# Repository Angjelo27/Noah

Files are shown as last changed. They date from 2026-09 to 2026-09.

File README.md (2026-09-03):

# NOAH - Offline Emergency First-Aid Terminal

**by American Labs · [american.al](https://american.al)**

NOAH is a fully offline, battery-friendly field terminal that answers emergency
first-aid questions in **Albanian and English**. It runs a local LLM with
retrieval over trusted first-aid references on an NVIDIA Jetson Orin Nano,
displays on a 7.8" e-ink panel, and takes input from a pocket keyboard. No
internet, no cloud, no account - press the button, type the question, get the
steps.

## Why

In an emergency without connectivity - mountains, blackouts, disasters - the
knowledge in books like *Where There Is No Doctor* is life-saving but hard to
search when your hands are shaking. NOAH turns that library into a device you
can ask in your own words, in the language you panic in.

## What it does

- **Ask in Albanian or English**, typed on a small Bluetooth keyboard; language
  is detected automatically and answers come back in the language you asked in.
- **Grounded answers**: a local llama3.2:3b answers strictly from retrieved
  passages of bundled first-aid references (IFRC 2025, WHO PFA, Werner, FEMA,
  FM 21-76 survival manual) - ~4,800 indexed chunks.
- **A deterministic safety layer above the model**: 50 keyword-triggered
  emergency rules with pre-written bilingual warnings (CPR, choking, stroke,
  poisoning, button batteries, ketoacidosis, hanging, chemical eye burns…),
  9 full answer replacements for known model failure modes, a scrubber that
  deletes dangerous model sentences (e.g. "make him vomit", "apply a
  tourniquet"), and a veto system so specific rules silence contradicting
  generic ones. Built and hardened across 13 adversarial audit rounds.
- **E-ink UI** designed for the field: word-at-a-time typing refresh,
  full-screen self-healing repaints, silent suspend on a short button press,
  and a persistent "POWERED OFF" screen (e-ink keeps its image with no power).
- **Runs cold**: boot to ready ≈ 60 s; wake from suspend ≈ 3 s with the model
  still warm; English answers in ~7-18 s, Albanian ~25-40 s (translation
  sandwich via NLLB-200).

## Repository layout

| Folder | Contents |
|---|---|
| [`software/`](software/) | All device code (UI, pipeline, safety layer, driver), systemd units, eval harness. Setup guide in its README. |
| [`hardware/`](hardware/) | [Bill of materials](hardware/BOM.md), [wiring guide](hardware/wiring.md), [assembly notes](hardware/assembly.md). |
| [`3d-models/`](3d-models/) | Printable STLs for the full enclosure (shell, visor, plates, bumpers, fit-test coupons) + the Blender source. |
| [`docs/`](docs/) | [Architecture](docs/architecture.md) and the [safety system](docs/safety-system.md) in detail. |

## Quick start

1. Print the enclosure - see [`3d-models/README.md`](3d-models/README.md).
2. Buy the parts - see [`hardware/BOM.md`](hardware/BOM.md).
3. Wire the panel, button and LEDs - see [`hardware/wiring.md`](hardware/wiring.md).
4. Flash JetPack and install the software - see [`software/README.md`](software/README.md).

## ⚠️ Disclaimer

**NOAH is an experimental, educational DIY project - it is not a medical
device and has not been reviewed or certified by any medical authority.**
Its answers come from a small language model constrained by a hand-built
safety layer; errors, mistranslations and omissions are possible and have
been observed during development. It must never replace professional medical
care, emergency services, or first-aid training. If you build one, have its
output reviewed by a medical professional, and treat it as a backup for
situations where no better help is available. The authors accept no
liability for its use.

The first-aid reference texts are **not** included in this repository for
copyright reasons; the software README lists where to obtain each one.

## License

Code and 3D models: [MIT](LICENSE). The NOAH name and logo belong to
American Labs.

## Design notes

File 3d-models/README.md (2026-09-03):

# 3D models

`NOAH_Terminal.blend` is the Blender source (millimeter scene, 1 unit = 1 mm).
The STLs are exported print-ready in real-world millimeters.

## Parts

| File | Part | Material |
|---|---|---|
| `STL/NOAH_Shell.stl` | Main clamshell body (print whole on ≥300 mm beds) | PETG |
| `Shell_Cuts/ShellV_*, ShellH_*, ShellQ_*` | The same shell pre-cut in halves/quarters for smaller printers - pick ONE scheme | PETG |
| `STL/NOAH_FrontPlate.stl` | Front plate with keyboard bay | PETG |
| `STL/NOAH_Visor.stl` | Screen visor (magnet-mounted) | PETG |
| `STL/NOAH_ScreenRetainer.stl` | Clamps the e-ink panel | PETG |
| `STL/NOAH_BasePlate.stl` | Bottom closure | PETG |
| `STL/NOAH_SidePlate_L.stl` / `_R.stl` | Side plates - **different designs, not mirrors** (L = camo, R = louver vents) | PETG |
| `STL/NOAH_RuggedTrim.stl`, `NOAH_Rugged_Trim.stl` | Edge trim | PETG |
| `STL/NOAH_LED_Lens.stl` | LED light pipe | Clear PETG/PLA |
| `bumpers/*`, `STL/NOAH_Bumper_*`, `STL/NOAH_RubberBumpers.stl` | Corner/edge/drop bumpers | **TPU** |
| `STL/NOAH_SolarTabLock_L/R.stl` | Solar panel retainers | PETG |
| `STL/NOAH_FitCoupon_*.stl` | Tolerance test pieces - **print these first** | any |

## Print settings (starting points)

- PETG: 0.2 mm layers, 4 perimeters, 25-40 % infill on structural parts.
- TPU bumpers: 0.2 mm, 2 perimeters, 15 % gyroid, slow.
- The shell prints without supports in its designed orientation; the visor
  face-down for a clean window edge.
- Run the fit coupons and tune horizontal expansion before the big parts:
  magnet pockets and the screen slot are tolerance-critical.

## Editing the source

The `.blend` targets Blender 4/5. The scene is unit-true (mm); part names
match the STL names. If you regenerate STLs, export with selection-only and
global scale 1.0.

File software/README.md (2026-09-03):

# NOAH software

Everything runs on the Jetson under a single systemd service. Paths assume
user `aldo` with code in `/home/aldo` - either create that user or search
and replace the paths in the `.py` files and service units.

## Components

| File | Role |
|---|---|
| `noah_ui.py` | The device UI: e-ink screens, keyboard input, power-button watcher (suspend / power-off screen), typing refresh, answer pagination. |
| `assistant.py` | Pipeline orchestration: language detect → translate → retrieve → LLM → safety post-processing → translate back. Deterministic small-talk replies. |
| `safety.py` | The deterministic safety layer: 50 bilingual emergency rules, 9 full answer replacements, dangerous-sentence scrubber, rule veto map, medication caution. Self-testing (`python3 safety.py` runs an 83-case matrix). |
| `translator.py` | Albanian↔English via NLLB-200 (CTranslate2 int8), language detection, idiom pre-rewrites, ~150 post-translation corrections. |
| `retrieval.py` | Hybrid retrieval: BM25 + Chroma vectors with reciprocal-rank fusion, query expansions, obsolete-doctrine filter. |
| `eink.py` | IT8951 e-ink driver (SPI + GPIO): 4bpp transfers, partial refresh, controller RAM map, GC16/DU waveforms. |
| `ingest.py` | Builds the vector/BM25 index from the reference PDFs (with a blocklist for outdated medical advice). |
| `recovery_strips.py` | Glass recovery tool: strip-by-strip black/white sweep (run with the service stopped). |
| `system/` | systemd units + logind config. |
| `eval/` | Eval harness + all bilingual question batteries from 13 audit rounds. |
| `tools/` | Controller diagnostics (RAM readback probes). |

## Setup

### 1. Base system

JetPack 6.x (Ubuntu 22.04) on a Jetson Orin Nano 8 GB. Then:

```bash
sudo apt update && sudo apt install -y python3-pip busybox librsvg2-bin
pip3 install chromadb requests pillow numpy rank_bm25 langdetect \
             ctranslate2 transformers sentencepiece Jetson.GPIO spidev
```

### 2. LLM runtime

```bash
curl -fsSL https://ollama.com/install.sh | sh
ollama pull llama3.2:3b
ollama pull nomic-embed-text
```

### 3. Translation model (Albanian)

Convert NLLB-200-distilled-600M to CTranslate2 int8 and place it at
`/data/models/nllb-ct2-int8`:

```bash
pip3 install "ctranslate2" "transformers[torch]"
ct2-transformers-converter --model facebook/nllb-200-distilled-600M \
  --output_dir /data/models/nllb-ct2-int8 --quantization int8
```

### 4. Reference library (not included - copyright)

Create `~/emergency-library/` and add:

- **IFRC International First Aid, Resuscitation and Education Guidelines 2025** - ifrc.org
- **WHO Psychological First Aid: Guide for Field Workers** - who.int
- **Where There Is No Doctor** (David Werner) - free from hesperian.org
- **FEMA "Are You Ready?"** - fema.gov (public domain)
- **FM 21-76 US Army Survival Manual** - public domain; trim to the
  medical/survival chapters to keep retrieval focused

Then build the index (stop ollama models you don't need first - ingest is
memory-hungry):

```bash
python3 ingest.py     # → ~/emergency-db (about 4,800 chunks)
```

### 5. Panel driver quirks (read before first boot)

- Set `VCOM_MV` in `eink.py` to YOUR panel's sticker value.
- The pinmux service is mandatory (see `hardware/wiring.md`).
- SPI stays at 4 MHz; the controller stores every frame as 8 bits/pixel
  internally - its 8 MB RAM fits exactly two frames. Do not add parked
  buffers; do not use partial-area displays from parked slots. These limits
  were mapped the hard way; `tools/` contains the probes that proved them.

### 6. Services

```bash
sudo cp system/noah-ui.service system/fix-gpio-pinmux.service /etc/systemd/system/
sudo mkdir -p /etc/systemd/logind.conf.d
sudo cp system/noah-power-logind.conf /etc/systemd/logind.conf.d/
sudo systemctl daemon-reload
sudo systemctl enable --now fix-gpio-pinmux noah-ui
sudo systemctl restart systemd-logind
```

Pair the BB Q10 keyboard once via `bluetoothctl` (`pair` + `trust`).

## Running the eval

```bash
cd eval
python3 sq_eval_runner.py sq_long_questions.txt /tmp/out.txt
```

`safety.py` doubles as a regression test: `python3 safety.py` must print
`ALL PASS` after any rule change. When you find a new failure mode, the
workflow is: add the rule/pattern + a matrix case + re-run the question -
that loop, repeated over 13 audit rounds, is where the safety layer came from.

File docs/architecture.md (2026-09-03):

# Architecture

```
 keyboard (BT HID) ──► noah_ui.py ──► assistant.answer(question)
                          │                   │
                          │            1. smalltalk? → canned bilingual reply
                          │            2. is_albanian? (word list + langdetect)
                          │            3. sq→en translation (NLLB ct2 int8)
                          │            4. first-person detection → patient stamp
                          │            5. hybrid retrieval (BM25 + Chroma, RRF)
                          │            6. llama3.2:3b via ollama (passages-only
                          │               for emergencies; general knowledge
                          │               allowed for everyday questions)
                          │            7. degeneration + short-answer retries
                          │            8. SAFETY LAYER (safety.py):
                          │               fired_rules → CONTRA replacement →
                          │               danger_scrub → med caution
                          │            9. en→sq translation + ~150 SQ fixes
                          │           10. prepend rule warnings (KUJDES blocks)
                          │                   │
                          ▼                   ▼
                    e-ink display  ◄── paginated answer
                    (IT8951 driver, eink.py)
```

## Key design decisions

- **Determinism above the model.** A 3B model cannot be trusted with
  life-safety edge cases. Every dangerous class discovered in testing became
  a regex-triggered pre-written warning that prints BEFORE the model text,
  independent of what the model says. The model provides depth; the rules
  provide the floor.
- **Translation sandwich.** The LLM never sees Albanian. Albanian in →
  English through NLLB → English answer → Albanian out, with idiom
  pre-rewrites (e.g. "i ra pika" = stroke, not a falling drop) and a large
  post-translation correction table, because a general MT model lacks the
  Albanian medical register.
- **E-ink discipline.** The IT8951 stores frames 8bpp: its 8 MB RAM holds
  exactly two frames (working + parked home). Full-screen single-pass deep
  refreshes exceed the prototype's 5 V wiring, so deep refreshes run as two
  half-screen GC16 passes; typing uses 16px-aligned A2 partial strips with a
  self-healing pass on every return home.
- **Power states.** Short button press = suspend (RAM + warm model kept,
  ~3 s wake). Long press = a persistent "powered off" screen - e-ink keeps
  the image at zero power - then clean shutdown.

## Timings (measured on the prototype)

| Event | Time |
|---|---|
| Cold boot → READY | ~60 s |
| Wake from suspend | ~3 s |
| English answer | 7-18 s |
| Albanian answer | 25-40 s |
| Deep home repaint | ~5.5 s |

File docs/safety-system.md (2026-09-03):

# The safety system

The heart of NOAH is not the language model - it is the deterministic layer
in [`safety.py`](../software/safety.py) that stands between the model and a
person in an emergency. It was built empirically across **13 adversarial
audit rounds** (hundreds of Albanian and English questions, every failure
fixed and locked with a regression test).

## Layers

1. **50 rules.** Each rule is `(name, english_pattern, albanian_pattern,
   english_warning, albanian_warning)`. Patterns run over both the raw
   question and its translation; a hit prepends a pre-written warning block
   before anything the model says. Coverage includes CPR/not-breathing,
   choking (with an explicit "coughing = don't interfere" clause), stroke
   (incl. folk idioms), poisoning (chemicals, pills, mushrooms, cigarettes,
   button batteries), bleeding, tourniquets, burns (thermal/chemical/sun),
   anaphylaxis, spinal, head injury, seizures, febrile seizures, diabetic
   low AND high sugar, hypothermia, frostbite, heatstroke, heat cramps,
   carbon monoxide, hanging, drowning, chest wounds, amputation, pregnancy
   (bleeding and falls), infants, testicular torsion, eye injuries (blunt
   and chemical), jellyfish, sea urchins, panic attacks, and more.
2. **9 CONTRA bodies.** For failure modes where the model was observed
   *commanding* the forbidden action (loosen the tourniquet, make them
   vomit, Heimlich for a stroke or a nose object), the entire model answer
   is replaced by a pre-written safe answer.
3. **danger_scrub.** Sentence-level deletion of known-dangerous model output
   regardless of context: negated-CPR advice, non-negated "make him vomit",
   "stop the birth", model-initiated tourniquets, "help them stand up"
   after falls, prompt echoes, plus a repetition-loop collapse.
4. **Veto map.** A specific rule silences a contradicting generic one
   (jellyfish ▸ burn - sea water vs fresh water; ketoacidosis ▸ hypoglycemia
   - no sugar vs give sugar; fishbone/nose-object ▸ choking).
5. **Medication caution.** Any answer naming prescription drugs gets a
   bilingual "not without a health worker" line appended.

## The regression matrix

`python3 safety.py` runs an 83-case matrix: real user phrasings (including
dialect, diacritic-free typing, reversed word order, first-person forms)
against expected rule sets, plus scrubber unit tests proving that safe
advice ("do NOT make them vomit") survives while dangerous advice is
deleted. **All changes must keep it at ALL PASS.** The matrix has caught
bugs in its own new rules before deployment more than once.

## Notable catches from the audit rounds

These are real outputs the layers now prevent - kept here as a reminder of
why the floor exists:

- "Loosen the tourniquet to let the blood circulate" (model, 3 of 3 runs)
- Heimlich maneuver for a stroke, a fish bone, and a bean in the nose
- "Do not attempt CPR if the person does not respond" (drowning)
- Glucose tablets for blood sugar 400 with acetone breath
- A tourniquet for an infected wound
- Drowning "float on your back" steps for a panic attack
- EpiPen advice for a heart attack
- Fresh-water rinse for a jellyfish sting
- "The device can't help, find somebody to talk to" for "I feel sick"

## Limits - be honest with users

The layer reduces risk; it cannot eliminate it. The model body under a
correct warning can still be clumsy or off-topic; translations still
produce occasional howlers; and no rule exists for classes nobody has
tested yet. Every transcript in `software/eval/` deserves a professional
medical read - if you build on this, continue the audit loop.

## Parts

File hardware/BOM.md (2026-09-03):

# Bill of Materials

| # | Part | Details | Qty |
|---|---|---|-----|
| 1 | **NVIDIA Jetson Orin Nano 8 GB Developer Kit** | The brain. Runs the LLM, translation and retrieval. NVMe SSD strongly recommended (models + index ≈ 10 GB). | 1 |
| 2 | **Waveshare 7.8" e-Paper HAT (B)** | IT8951 controller, 1872 × 1404, 16 grey levels. Panel + driver board + adapter. | 1 |
| 3 | **BB Q10 Bluetooth keyboard module** | BlackBerry Q10 keyboard with a Bluetooth controller board (sold as a DIY module). Pairs as a standard BT HID keyboard. | 1 |
| 4 | **USB-C PD power supply, 65 W with a 15 V profile** | ⚠️ See the power warning in [wiring.md](wiring.md) - cable choice matters. | 1 |
| 5 | **Momentary push button** | Panel-mount, normally-open. Wired to the Jetson's button header: suspend / wake / power-off / power-on. | 1 |
| 6 | **LEDs, 3 mm/5 mm + series resistors (≈330 Ω)** | Power LED and signal ("thinking") LED, front panel via the printed lens. | 2 |
| 7 | **Dupont jumper wires, female-female** | Panel SPI + power harness (10+), button, LEDs. For the permanent build, replace with a soldered harness. | ~20 |
| 8 | **Neodymium disc magnets** | Hold the screen visor to the shell (design uses 7). Size per the pockets in the printed parts - verify with `NOAH_FitCoupon_Magnet.stl` before committing. | 7 |
| 9 | *(Optional)* **Small solar panel** | The shell has integrated solar mounting tabs + printed tab locks. Any thin panel that fits the back recess; feeds a USB power bank, not the Jetson directly. | 1 |
| 10 | *(Optional)* **USB power bank, USB-C PD, 15 V capable** | For true field use. ⚠️ Read the 20 V cable warning in wiring.md **before** battery use. | 1 |

## Print-side consumables

- PETG (or PLA for indoor units) for the shell, visor, plates - see
  [`3d-models/README.md`](../3d-models/README.md).
- TPU for the rubber bumpers (`bumpers/`, `NOAH_RubberBumpers.stl`).
- M2/M3 screws per the boss holes in the shell (verify against your print).

## Tools

- Multimeter - genuinely required once: for continuity checks before the 5 V
  harness reinforcement and for **identifying safe charging cables** (see the
  20 V warning). A cheap one is fine.
- Soldering iron for the permanent harness (the prototype runs on dupont).

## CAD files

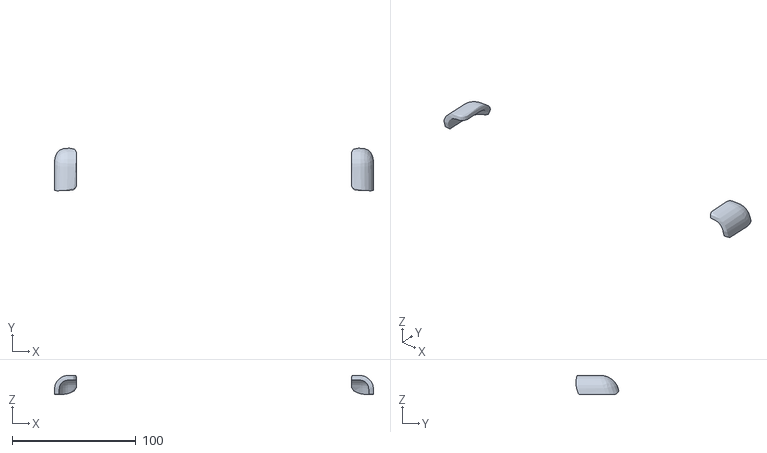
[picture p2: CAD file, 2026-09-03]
3d-models/bumpers/NOAH_Bumper_TopCap.stl
258.0 x 34.5 x 15.6

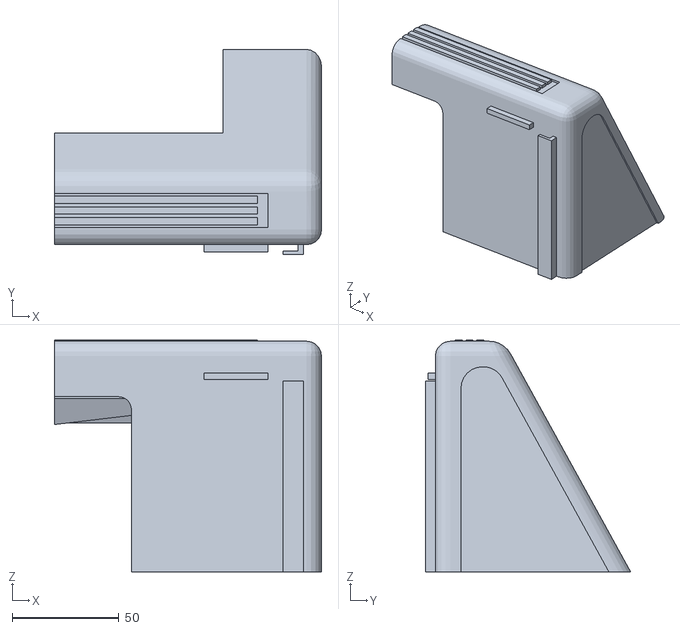
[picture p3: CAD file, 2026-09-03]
3d-models/Shell_Cuts/NOAH_ShellQ_Left_Top.stl
125.0 x 96.2 x 108.5

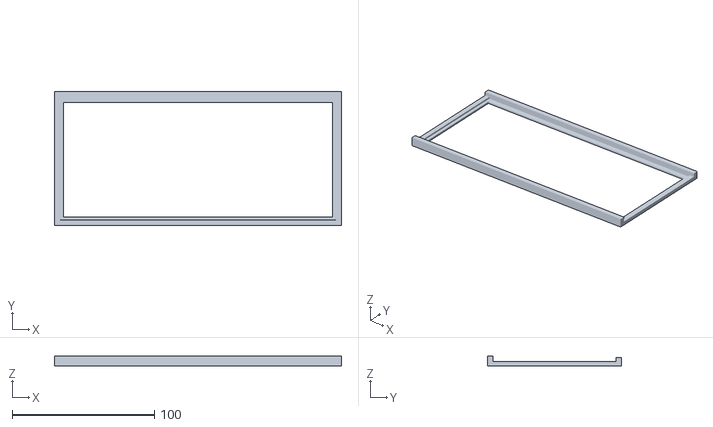
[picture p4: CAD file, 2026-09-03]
3d-models/STL/NOAH_FitCoupon_Keyboard.stl
202.0 x 94.6 x 7.00

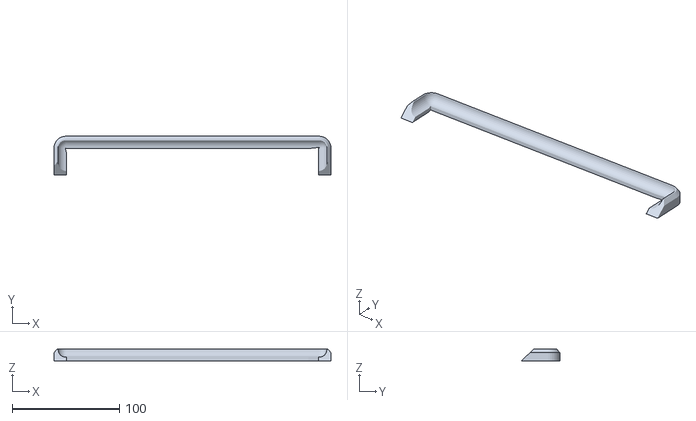
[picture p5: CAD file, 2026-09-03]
3d-models/bumpers/NOAH_Bumper_Bottom.stl
258.0 x 36.0 x 11.0

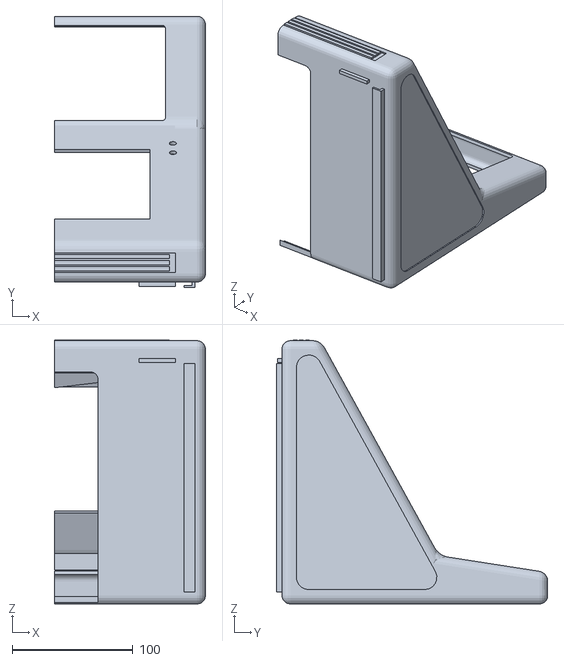
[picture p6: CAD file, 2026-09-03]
3d-models/Shell_Cuts/NOAH_ShellV_Left.stl
125.0 x 224.7 x 218.5

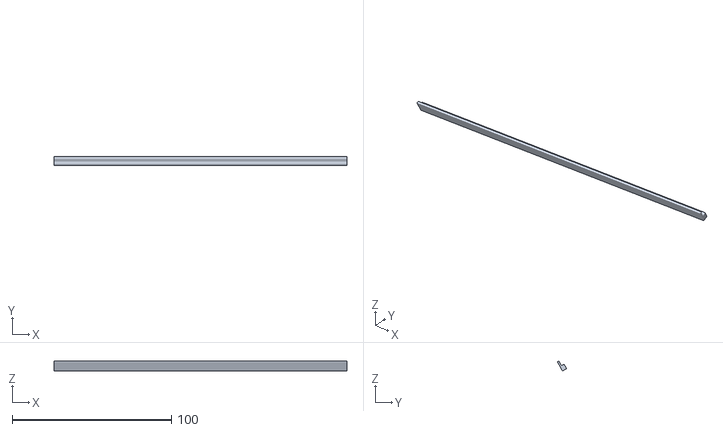
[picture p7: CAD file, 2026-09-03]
3d-models/STL/NOAH_ScreenRetainer.stl
184.0 x 5.79 x 6.27

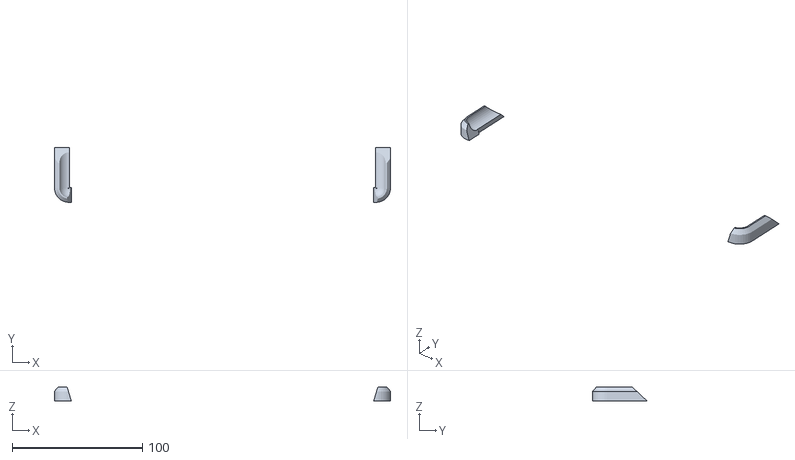
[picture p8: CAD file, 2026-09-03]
3d-models/bumpers/NOAH_Bumper_Back.stl
258.0 x 42.0 x 11.0

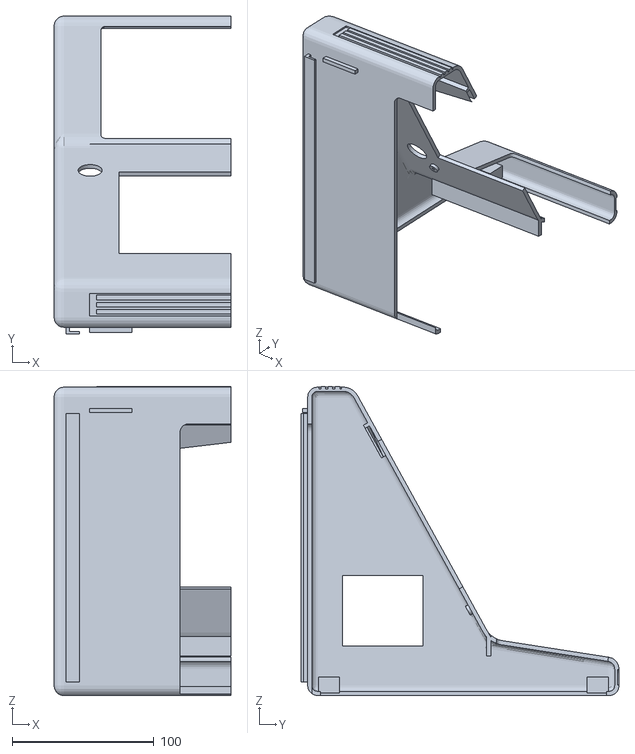
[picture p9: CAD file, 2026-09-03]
3d-models/Shell_Cuts/NOAH_ShellV_Right.stl
125.0 x 224.7 x 218.5

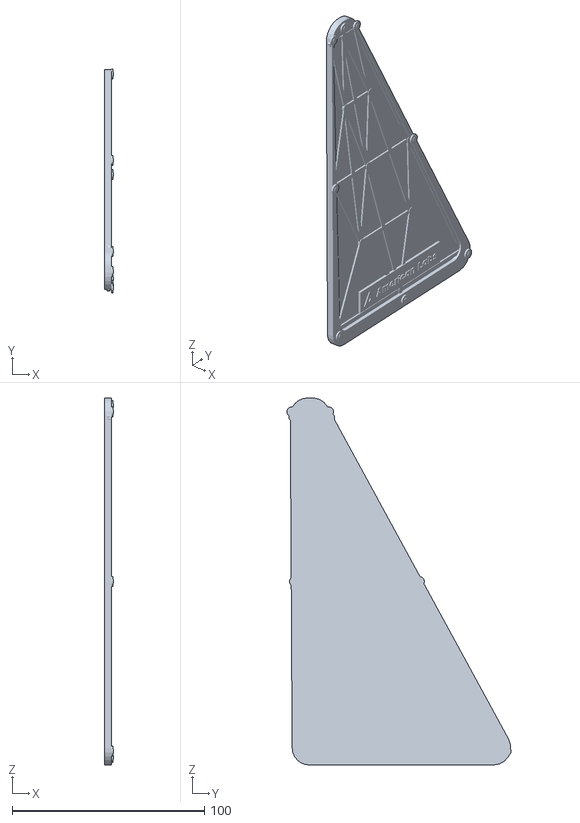
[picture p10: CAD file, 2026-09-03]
3d-models/STL/NOAH_SidePlate_L.stl
4.75 x 116.6 x 190.9

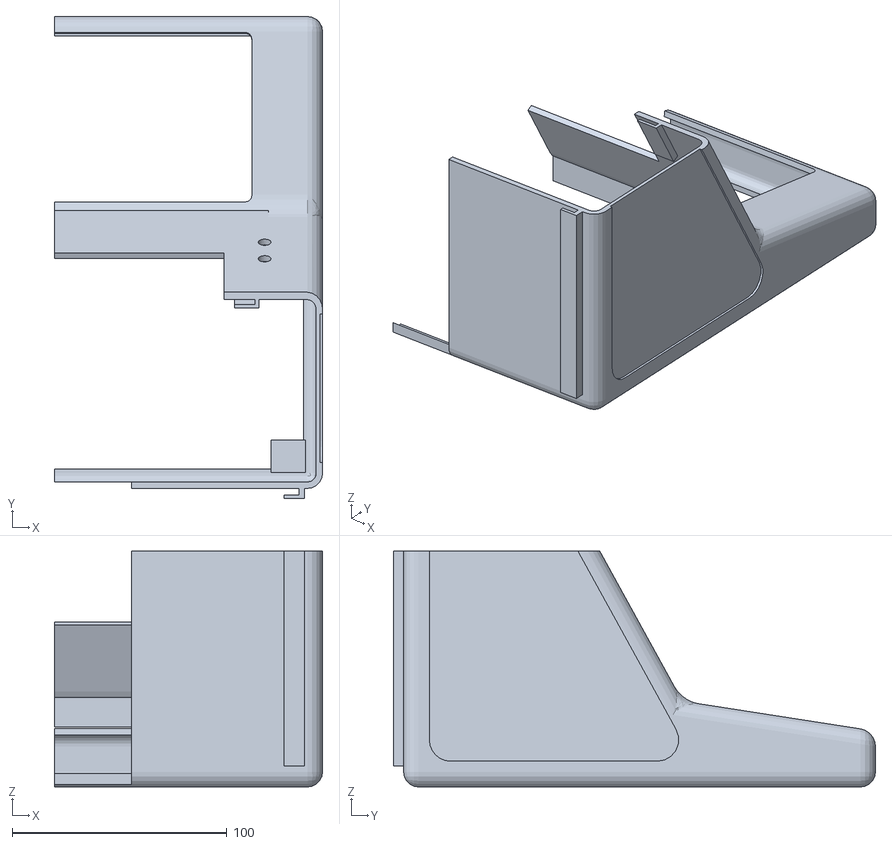
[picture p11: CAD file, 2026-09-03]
3d-models/Shell_Cuts/NOAH_ShellQ_Left_Bottom.stl
125.0 x 224.7 x 110.0

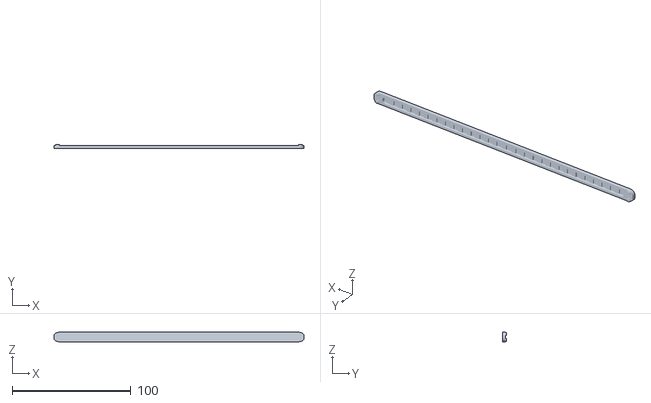
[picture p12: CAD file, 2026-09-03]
3d-models/STL/NOAH_FrontPlate.stl
210.3 x 3.40 x 8.00

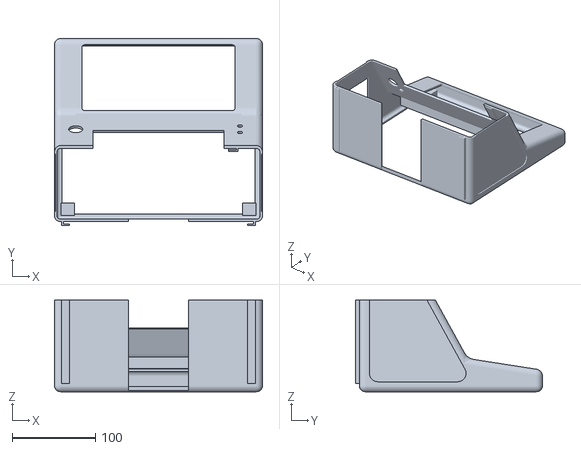
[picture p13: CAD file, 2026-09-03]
3d-models/Shell_Cuts/NOAH_ShellH_Bottom.stl
250.0 x 224.7 x 110.0

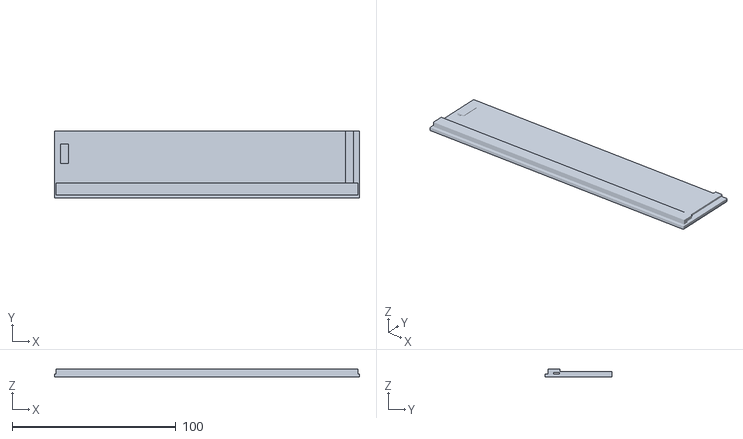
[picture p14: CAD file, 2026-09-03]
3d-models/STL/NOAH_FitCoupon_Screen.stl
186.0 x 41.0 x 5.00

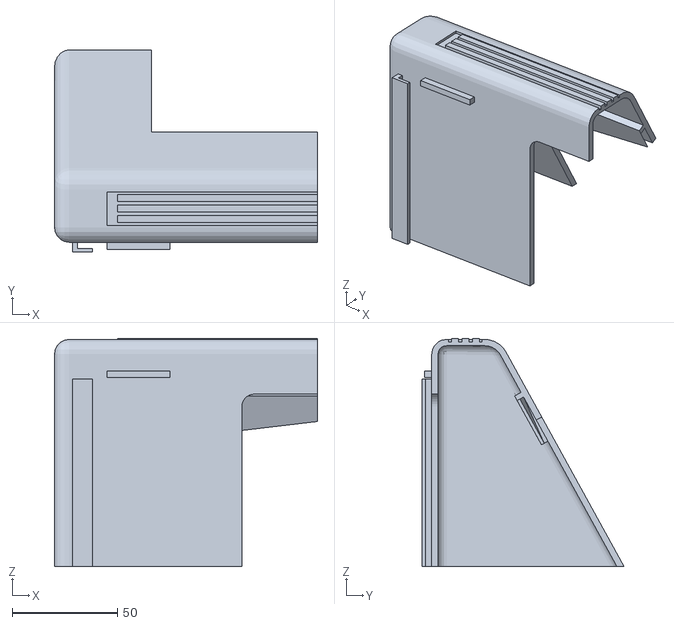
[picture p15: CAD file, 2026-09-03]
3d-models/Shell_Cuts/NOAH_ShellQ_Right_Top.stl
125.0 x 96.2 x 108.5

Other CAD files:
3d-models/STL/NOAH_FitCoupon_Magnet.stl
3d-models/Shell_Cuts/NOAH_ShellQ_Right_Bottom.stl
3d-models/STL/NOAH_SolarTabLock_L.stl
3d-models/Shell_Cuts/NOAH_ShellH_Top.stl
3d-models/NOAH_Terminal.blend
3d-models/STL/NOAH_BasePlate.stl
3d-models/STL/NOAH_FitCoupon_Rails.stl
3d-models/STL/NOAH_LED_Lens.stl
3d-models/STL/NOAH_RubberBumpers.stl
3d-models/STL/NOAH_RuggedTrim.stl
3d-models/STL/NOAH_Rugged_Trim.stl
3d-models/STL/NOAH_Shell.stl
3d-models/STL/NOAH_SidePlate_R.stl
3d-models/STL/NOAH_SolarTabLock_R.stl
3d-models/STL/NOAH_Visor.stl

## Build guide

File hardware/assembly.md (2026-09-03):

# Assembly notes

The enclosure is a printed clamshell: main shell + front plate + screen visor
+ base plate + two side plates + TPU bumpers. Fit is magnet-and-rail based -
no glue on the main joints.

## Before printing everything

Print the **fit coupons first** (`3d-models/STL/NOAH_FitCoupon_*.stl`):
screen, keyboard, magnet and rail coupons. They are small test pieces that
verify your printer's tolerances against the real hardware before you spend
a spool on the shell. Adjust horizontal expansion until the coupons fit
snugly.

## Order of assembly

1. **Dry-fit the electronics** outside the shell first: wire the panel per
   [wiring.md](wiring.md), boot, and confirm the display works. Debugging
   through an assembled shell is misery.
2. **Screen + visor**: the panel sits in the front opening, held by
   `NOAH_ScreenRetainer.stl`; the visor (`NOAH_Visor.stl`) carries the
   window and clicks onto the shell with the 7 magnets (pockets in both
   parts - glue magnets with CA, mind the polarity, check twice before the
   glue sets).
3. **Jetson + driver board** mount inside the main shell (`NOAH_Shell.stl`)
   on the printed rails/bosses. The IT8951 driver board sits behind the
   panel; keep the panel FPC gentle - no sharp folds.
4. **Keyboard bay**: the BB Q10 module drops into the keyboard bay in the
   front plate (`NOAH_FrontPlate.stl`). It is wireless - only its charging
   lead needs routing.
5. **Button + LEDs**: the momentary button mounts in its shell hole and wires
   to the J14 header; the two LEDs sit behind `NOAH_LED_Lens.stl`.
6. **Side plates** (`NOAH_SidePlate_L/R.stl`) - note they are DIFFERENT
   designs, not mirrors: left is the camo plate, right carries the louver
   vents. They close the sides after the harness is in.
7. **Base plate** (`NOAH_BasePlate.stl`) closes the bottom.
8. **Bumpers**: TPU corner/edge bumpers (`bumpers/`, plus
   `NOAH_Bumper_*.stl`) press onto the shell - print them last, they hide
   layer seams and take the drops.
9. *(Optional)* **Solar**: thin panel into the back recess, held by
   `NOAH_SolarTabLock_L/R.stl`.

## Shell print variants

`Shell_Cuts/` contains the shell pre-cut for smaller printers: vertical
halves (`ShellV_*`), horizontal halves (`ShellH_*`), or quarters
(`ShellQ_*`). Pick ONE scheme; the cuts have alignment features. On a
300 mm-class bed, print `NOAH_Shell.stl` whole.

## The cable rule

Whatever harness you build: label the known-good power cable, and keep the
20 V warning from [wiring.md](wiring.md) taped to the battery.

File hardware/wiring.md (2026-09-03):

# Wiring guide

All references are to the Jetson Orin Nano Developer Kit. Header pins are
counted from the printed "1" on the carrier board (odd/even rows). **Never
connect or disconnect anything with power applied.**

## 1. E-ink panel (Waveshare IT8951 HAT (B))

The HAT is *not* stacked on the 40-pin header - it is wired with individual
jumpers so the enclosure can position it freely. The HAT header follows the
Raspberry Pi layout, so pin numbers match on both ends.

| Signal | Jetson 40-pin | HAT pin | Notes |
|---|---|---|---|
| 5V | pin 2 (and 4) | 5V (2/4) | ⚠️ One jumper sags under load - see §4. |
| GND | pin 6 (add 9/14) | GND (6/9/14) | More grounds = better. |
| SCK | pin 23 (SPI1_SCK) | CLK | 4 MHz max on jumper wiring - 12 MHz corrupts commands. |
| MOSI | pin 19 (SPI1_MOSI) | DIN | |
| MISO | pin 21 (SPI1_MISO) | DOUT | |
| CS | pin 24 | CS | Driven as GPIO (gpiochip0 line 136), not hardware CS. |
| RST | pin 11 | RST | gpiochip0 line 112. |
| BUSY (HRDY) | pin 13 | BUSY | gpiochip0 line 122. |

Panel specifics baked into the driver ([`software/eink.py`](../software/eink.py)):
VCOM **−1.58 V** (read your own panel's sticker and change `VCOM_MV`!),
SPI 4 MHz, 4-bits-per-pixel transfers.

**Pinmux is mandatory.** JetPack boots these pads in the wrong function; the
included [`fix-gpio-pinmux.service`](../software/system/fix-gpio-pinmux.service)
writes the pad registers with `busybox devmem` at every boot (SPI1 pads to
SFIO, CS and RST to GPIO, LED pads). Without it the panel reads all zeros.
Do not rely on `jetson-io` overlays - on this system they silently fail to
apply at boot.

## 2. Power button

A momentary switch across the **PWR BTN ↔ GND pins of the 12-pin button
header (J14)**. Behavior is implemented in software (`noah_ui.py` watches the
key events; systemd-logind is told to ignore the key):

- Short press: silent suspend / wake (model stays warm, ~3 s to usable).
- Hold ≈ 3 s: draws a persistent "FIKUR · POWERED OFF" screen, then clean
  shutdown. The image stays on the e-ink while the device is off.
- Short press while off: powers back on.

## 3. LEDs

| LED | Jetson pin (BOARD) | Notes |
|---|---|---|
| Power | 31 | Series resistor ≈ 330 Ω to GND. |
| Signal ("thinking") | 7 | Blinks while an answer is being generated. |

Both shine through the printed `NOAH_LED_Lens.stl`.

## 4. Power - read this twice

- Supply: USB-C PD, **15 V profile** (65 W class). The Jetson barrel/USB-C
  input takes it directly.
- ⚠️ **The 20 V cable trap.** Some USB-C cable + supply combinations negotiate
  **20 V**, which is above the dev kit's rating. During development one cable
  was found doing exactly that. Before running from any battery or new
  supply: verify the negotiated voltage with a USB-C power meter or
  multimeter, and physically mark known-good cables. Never power NOAH from
  an unverified cable.
- ⚠️ **5 V panel feed.** The e-ink drive current over a single 5 V jumper
  causes voltage sag: full-screen deep refreshes abort, and at the worst
  point half-screen refreshes failed silently. The software works around it
  (half-screen deep refreshes only), but the real fix is copper: run 5 V
  from **both** pin 2 and pin 4 and grounds from pins 6 + 9 + 14 (parallel
  jumpers), or better, a soldered harness. After reinforcement, the software
  can be switched to single-pass full-screen refreshes.

## 5. Assembly order

See [assembly.md](assembly.md).

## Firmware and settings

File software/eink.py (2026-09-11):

#!/usr/bin/env python3
"""NOAH e-ink renderer - IT8951 (7.8" 1872x1404) over SPI on Jetson Orin Nano.

Proven protocol recipe (2026-08-26 bring-up):
  * 4 MHz SPI max on current wiring; wait HRDY before EVERY preamble
  * bulk pixel writes framed per 2 KB chunk (preamble each chunk)
  * displays via DPY_BUF_AREA 0x0037 only (0x0034 dies after first use)
  * VCOM must be programmed (-1.58 V) every panel power-on
  * DU (mode 1) / A2 (mode 6) complete on current 5 V wiring; full-screen
    GC16 (mode 2) aborts until the power feed is upgraded - use DU for text.

Usage:
    from eink import EInk
    epd = EInk()
    pages = epd.paginate_text(answer, title=question, footer="sources: ...")
    epd.show(pages[0])          # DU refresh, auto ghost management
    epd.close()

CLI self-test:  sudo python3 eink.py ["text to render"]
"""
import re, time
import spidev, gpiod
import numpy as np
from PIL import Image, ImageDraw, ImageFont

RST_LINE, CS_LINE, BUSY_LINE = 112, 136, 122     # gpiochip0 (pins 11 / 24 / 13)
VCOM_MV = 1580                                    # panel sticker: -1.58 V
SPI_HZ = 4000000
W, H = 1872, 1404

MODE_INIT, MODE_DU, MODE_GC16, MODE_A2 = 0, 1, 2, 6

FONT_DIR = "/usr/share/fonts/truetype/dejavu/"
MARGIN, TITLE_SIZE, BODY_SIZE, FOOT_SIZE = 118, 48, 40, 28  # 118px = 1cm @ 300dpi
LINE_PITCH = 54
GHOST_FLUSH_EVERY = 8      # white-flush before every Nth refresh


class EInk:
    def __init__(self, vcom=VCOM_MV, spi_hz=SPI_HZ):
        # Null the handles first so a failure partway can release cleanly. An
        # early-boot init can hit a transient EBUSY (the SPI1 pads are still
        # settling right after the pinmux switch): if that happens AFTER the
        # gpio lines are requested, leaving them held would make every retry
        # fail with EBUSY on our own lines. Release on any init failure.
        self._chip = self._rst = self._cs = self._busy = self._spi = None
        try:
            self._chip = gpiod.Chip("gpiochip0")
            self._rst = self._chip.get_line(RST_LINE)
            self._cs = self._chip.get_line(CS_LINE)
            self._busy = self._chip.get_line(BUSY_LINE)
            self._rst.request(consumer="eink", type=gpiod.LINE_REQ_DIR_OUT, default_vals=[1])
            self._cs.request(consumer="eink", type=gpiod.LINE_REQ_DIR_OUT, default_vals=[1])
            self._busy.request(consumer="eink", type=gpiod.LINE_REQ_DIR_IN)
            self._spi = spidev.SpiDev()
            self._spi.open(0, 0)
            self._spi.mode = 0
            self._spi.max_speed_hz = spi_hz
            self.refreshes = 0

            # Reset + boot, then read device info. BOTH the wake (HRDY) and the
            # GET_DEV_INFO read can glitch at cold boot: a desynced SPI read
            # returns shifted words (observed: height read back as 1872 instead
            # of 1404), which used to FATAL the whole UI and force a restart.
            # Retry the entire reset -> SYS_RUN -> GET_DEV_INFO on a bad read.
            info = None
            for attempt in range(4):
                self._rst.set_value(0); time.sleep(0.2)
                self._rst.set_value(1); time.sleep(0.1)
                try:
                    self._ready(4.0)
                except RuntimeError:
                    if attempt == 3:
                        raise RuntimeError("IT8951 not ready after 4 reset attempts")
                    continue
                self._wcmd(0x0001)                   # SYS_RUN
                self._wcmd(0x0302)                   # GET_DEV_INFO
                info = self._rdata(20)
                if (info[0], info[1]) == (W, H) and ((info[3] << 16) | info[2]):
                    break                            # good, synced read
                if attempt == 3:
                    raise RuntimeError("bad device info after 4 tries: %s" % info[:4])
                time.sleep(0.15)                     # desynced read: reset & retry
            self.width, self.height = info[0], info[1]
            self.imgbuf = (info[3] << 16) | info[2]
            self._wreg(0x0004, 0x0001)               # I80CPCR: packed write
            self._wcmd(0x0039); self._wdata(0x0001); self._wdata(vcom)   # set VCOM
        except BaseException:
            self._release_partial()
            raise

        self._fonts = {
            "title": ImageFont.truetype(FONT_DIR + "DejaVuSans-Bold.ttf", TITLE_SIZE),
            "body":  ImageFont.truetype(FONT_DIR + "DejaVuSans.ttf", BODY_SIZE),
            "foot":  ImageFont.truetype(FONT_DIR + "DejaVuSansMono.ttf", FOOT_SIZE),
        }

    def _release_partial(self):
        """Release whatever __init__ managed to acquire, on a failed init."""
        try:
            if self._spi is not None:
                self._spi.close()
        except Exception:
            pass
        for ln in (self._rst, self._cs, self._busy):
            try:
                if ln is not None:
                    ln.release()
            except Exception:
                pass
        try:
            if self._chip is not None:
                self._chip.close()
        except Exception:
            pass

    # ---------- low-level protocol ----------
    def _ready(self, tmo=6.0):
        t0 = time.time()
        while time.time() - t0 < tmo:
            if self._busy.get_value() == 1:
                return
        raise RuntimeError("IT8951 HRDY timeout")

    def _frame(self, preamble, payload):
        self._ready(); self._cs.set_value(0)
        self._spi.xfer2(list(preamble)); self._ready()
        self._spi.xfer2(list(payload)); self._cs.set_value(1)

    def _wcmd(self, v):  self._frame((0x60, 0x00), (v >> 8, v & 0xFF))
    def _wdata(self, v): self._frame((0x00, 0x00), (v >> 8, v & 0xFF))

    def _rdata(self, n):
        self._ready(); self._cs.set_value(0)
        self._spi.xfer2([0x10, 0x00]); self._ready()
        self._spi.xfer2([0, 0]); self._ready()
        raw = self._spi.xfer2([0] * (2 * n)); self._cs.set_value(1)
        return [(raw[i] << 8) | raw[i + 1] for i in range(0, 2 * n, 2)]

    def _wreg(self, a, v): self._wcmd(0x0011); self._wdata(a); self._wdata(v)
    def _rreg(self, a):    self._wcmd(0x0010); self._wdata(a); return self._rdata(1)[0]

    # ---------- image path ----------
    def _load(self, img, x=0, y=0, addr=None):
        """img: np.uint8 (h, w), row-major, 0=black 255=white. 4bpp transfer
        (half the bytes of 8bpp - text is thresholded B/W, no quality loss)."""
        h, w = img.shape
        addr = self.imgbuf if addr is None else addr
        self._wreg(0x0208, addr & 0xFFFF)
        self._wreg(0x020A, addr >> 16)
        self._wcmd(0x0021)                       # LD_IMG_AREA
        for v in (0x0020, x, y, w, h):           # little-endian, 4bpp, rot0
            self._wdata(v)
        nib = (img >> 4).astype(np.uint8)        # 0x0 / 0xF
        packed = (nib[:, 0::2] | (nib[:, 1::2] << 4)).tobytes()
        data = np.frombuffer(packed, dtype="<u2").byteswap().tobytes()
        for off in range(0, len(data), 2048):
            self._ready(); self._cs.set_value(0)
            self._spi.xfer2([0x00, 0x00]); self._ready()
            self._spi.writebytes(data[off:off + 2048])
            self._cs.set_value(1)
        self._wcmd(0x0022)                       # LD_IMG_END

    def _display(self, mode, x=0, y=0, w=W, h=H, tmo=20.0, addr=None):
        addr = self.imgbuf if addr is None else addr
        self._wcmd(0x0037)                       # DPY_BUF_AREA
        for v in (x, y, w, h, mode, addr & 0xFFFF, addr >> 16):
            self._wdata(v)
        t0 = time.time(); first = last = None
        while time.time() - t0 < tmo:
            if self._rreg(0x1224):
                t = time.time() - t0
                if first is None: first = t
                last = t
            elif first is not None and (time.time() - t0 - last) > 0.5:
                break
        return 0.0 if first is None else last - first

    def clear(self):
        """Full white via double DU pass (works on current power wiring)."""
        white = np.full((H, W), 0xFF, dtype=np.uint8)
        self._load(white)
        self._display(MODE_DU)
        self._display(MODE_DU)

    def show(self, img, mode=MODE_DU):
        """Load and display a full frame with automatic ghost management."""
        if self.refreshes and self.refreshes % GHOST_FLUSH_EVERY == 0:
            self.clear()
        self._load(img)
        dur = self._display(mode)
        self.refreshes += 1
        return dur

    # --- dual-buffer page slots: preload while reading, flip in ~0.5s ---
    SLOT_STRIDE = 0x290000  # TRUE 8bpp frame footprint 0x281AC0 + pad. RAM fits ONLY slots 0 (imgbuf) and 1 - see 2026-08-29 probe; never add more

    def load_page(self, img, slot=0):
        self._load(img, addr=self.imgbuf + slot * self.SLOT_STRIDE)

    def show_slot(self, slot=0, mode=MODE_DU):
        return self._display(mode, addr=self.imgbuf + slot * self.SLOT_STRIDE)

    def deep_clean(self):
        """Two half-screen GC16 passes - heavier ghost flush (half current draw)."""
        white = np.full((H, W), 0xFF, dtype=np.uint8)
        self._load(white)
        self._display(MODE_GC16, 0, 0, W, H // 2)
        self._display(MODE_GC16, 0, H // 2, W, H // 2)

    def close(self):
        # No STANDBY: wake-from-standby proved flaky; idle draw is acceptable
        # and the field device will gate panel power in hardware anyway.
        self._spi.close()
        for ln in (self._rst, self._cs, self._busy):
            ln.release()
        self._chip.close()

    # ---------- text rendering ----------
    def _wrap(self, draw, text, font, maxw):
        lines = []
        for raw in text.split("\n"):
            if not raw.strip():
                lines.append("")
                continue
            m = re.match(r"^(\s*(?:\d+[.)]\s+|[-*•]\s+)?)", raw)
            hang = " " * max(2, len(m.group(1))) if m.group(1).strip() else ""
            words, cur = raw.split(), ""
            firstline = True
            for wd in words:
                cand = (cur + " " + wd).strip() if cur else (wd if firstline else hang + wd)
                probe = cand if firstline else cand
                if draw.textlength(probe, font=font) <= maxw or not cur:
                    cur = cand
                else:
                    lines.append(cur)
                    firstline = False
                    cur = hang + wd
            lines.append(cur)
        return lines

    def paginate_text(self, text, title=None, footer=None):
        """Render text into 1..N full-frame numpy pages (thresholded B/W)."""
        probe = ImageDraw.Draw(Image.new("L", (8, 8)))
        maxw = W - 2 * MARGIN
        body_lines = self._wrap(probe, text, self._fonts["body"], maxw)

        top = MARGIN
        title_lines = []
        if title:
            title_lines = self._wrap(probe, title.strip(), self._fonts["title"], maxw)[:2]
            top += len(title_lines) * (TITLE_SIZE + 10) + 26
        usable = H - top - (FOOT_SIZE + 30 + MARGIN)
        per_page = max(1, usable // LINE_PITCH)
        chunks = [body_lines[i:i + per_page] for i in range(0, len(body_lines), per_page)] or [[]]

        pages = []
        for pi, chunk in enumerate(chunks):
            im = Image.new("L", (W, H), 255)
            d = ImageDraw.Draw(im)
            y = MARGIN
            for tl in title_lines:
                d.text((MARGIN, y), tl, font=self._fonts["title"], fill=0)
                y += TITLE_SIZE + 10
            if title_lines:
                d.line((MARGIN, y + 6, W - MARGIN, y + 6), fill=0, width=4)
                y += 26
            for ln in chunk:
                d.text((MARGIN, y), ln, font=self._fonts["body"], fill=0)
                y += LINE_PITCH
            fy = H - MARGIN - FOOT_SIZE
            avail = maxw
            n = len(chunks)
            foot_txt = footer
            if n > 1:                            # multi-page: counter + nav hint
                pg = "%d/%d" % (pi + 1, n)
                pgw = probe.textlength(pg, font=self._fonts["foot"])
                d.text((W - MARGIN - pgw, fy), pg, font=self._fonts["foot"], fill=0)
                avail = maxw - pgw - 60
                if pi < n - 1:                   # a next page exists
                    foot_txt = "ENTER/SPACE = tjetra / next"
                    if pi > 0:                   # ...and a previous page
                        foot_txt += "   P = mbrapa / prev"
                else:                            # last page
                    foot_txt = "P = mbrapa / prev   ENTER = kthehu / back"
            if foot_txt:
                ftxt = foot_txt
                if probe.textlength(ftxt, font=self._fonts["foot"]) > avail:
                    while ftxt and probe.textlength(ftxt + "…", font=self._fonts["foot"]) > avail:
                        ftxt = ftxt[:-1]
                    ftxt += "…"
                d.text((MARGIN, fy), ftxt, font=self._fonts["foot"], fill=0)
            arr = np.frombuffer(im.tobytes(), dtype=np.uint8).reshape(H, W)
            pages.append(np.where(arr > 160, 255, 0).astype(np.uint8))
        return pages


if __name__ == "__main__":
    import sys
    sample = sys.argv[1] if len(sys.argv) > 1 else (
        "Cool the burn immediately with clean, cool running water.\n\n"
        "1. Hold the burned area under cool (not icy) running water for at least 20 minutes.\n"
        "2. Remove rings, watches and tight clothing near the burn before it swells.\n"
        "3. Do NOT apply ice, butter, toothpaste or any ointment to the burn.\n"
        "4. Cover the burn loosely with a clean, non-fluffy cloth or cling film.\n"
        "5. Give the person small sips of water if they are alert.\n\n"
        "Seek professional medical help if the burn is larger than the person's palm, "
        "is on the face, hands or joints, looks white or charred, or if the person "
        "shows signs of shock: pale skin, rapid breathing, confusion.")
    epd = EInk()
    print("panel %dx%d ready, rendering test page..." % (epd.width, epd.height))
    pages = epd.paginate_text(
        sample, title="How do I treat a burn?",
        footer="sources: IFRC International First Aid, Resuscitation and Education "
               "Guidelines 2025, Where_There_Is_No_Doctor_A_Village_Health_Care_Handbook")
    t0 = time.time()
    dur = epd.show(pages[0])
    print("page 1/%d shown (load+refresh %.1fs, engine %.1fs)" % (len(pages), time.time() - t0, dur))
    epd.close()
    print("PASS - the panel should show a formatted first-aid page")

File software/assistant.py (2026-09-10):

import os, re, requests, chromadb, threading, time
import Jetson.GPIO as GPIO
import sys
sys.path.insert(0, "/home/aldo/.local/lib/python3.10/site-packages")  # sudo cant see user pip
import translator
import safety
import retrieval

DB_PATH = "/home/aldo/emergency-db"
OLLAMA = "http://localhost:11434"
MODEL = "llama3.2:3b"          # multilingual (Albanian); was llama3.2:3b
TOP_K = 4
LED_SIGNAL = 7
LED_POWER = 31

SYSTEM_PROMPT = """You are NOAH, an offline emergency first-aid assistant running on a device with no internet access. Your EMERGENCY answers must be drawn ONLY from the reference passages provided below.

FIRST classify the message:
- EMERGENCY: an injury, illness, symptom, accident, or danger happening now. Follow ALL the emergency rules below.
- GENERAL: prevention, supplies, training, everyday habits (food, drink, coffee, sleep, exercise), or general health knowledge. Answer with a short informative paragraph of 4-8 sentences (or a few bullet points): the key facts, practical amounts and numbers, and one or two useful extras such as what to avoid or when it matters. Never answer a GENERAL question with a single sentence. Do not use the emergency format - no urgent-action opener, no numbered emergency steps, no warning-signs section. For GENERAL questions only: if the reference passages are not relevant to the question, IGNORE them completely and answer from ordinary general knowledge - never force emergency framing into an everyday question (no "in emergency situations" talk unless the user described an emergency). Questions about you ("what can you do", "who are you", "how do you work") get 1-2 sentences describing what you are - an offline first-aid guide that answers emergency questions in Albanian and English - NEVER first-aid instructions, even if the reference passages contain them.

TONE, always: straight to the point and factual. No sympathy lines, no reassurance filler ("stay calm", "I am worried about you"), no apologies, no praise, no exclamation marks, no chit-chat. Every sentence must carry an instruction or a fact.

PERSPECTIVE, always: match who is affected. If the user describes THEIR OWN symptoms ("I feel sick", "my arm is bleeding", "I am dizzy"), speak directly to them as "you" - never about "the person", "him", "her", "the victim" or "the patient". If they describe someone else's emergency, give the user the helper's instructions. NEVER deflect with "find someone to help you", "ask someone else" or "talk to somebody" - the user has only this device; always give the actual steps themselves.

EMERGENCY RULES:
1. Answer ONLY using the reference passages. Never invent facts, procedures, medication names, or doses. If the passages give a specific number, use it exactly.
2. If the passages do not cover the situation, say clearly: "My references don't cover this specific situation." Then give the safest general action and state that professional medical help is needed.
3. Start with the single most urgent action in one short sentence. ONLY IF the question asks whether to do something ("should I...", "can I...", "is it safe to...") begin with "Yes" or "No" and the reason. For any other question do NOT begin with the word "Yes" or "No" - begin directly with the action itself. A prohibition like "Do NOT pull it out" counts as the urgent action.
4. Then give numbered steps in the order they must be done. One action per step. Short sentences. Commands, not suggestions.
5. Use plain language a scared non-expert can follow. Translate medical terms. NEVER drop a "do not" warning from the passages.
6. If the passages contain conflicting advice, prefer the IFRC 2025 guidelines over older sources. Older techniques like induced vomiting for poisoning or loosening tourniquets are outdated - do not recommend them.
7. End by stating when to seek professional medical help and warning signs of worsening.
8. Users may type short, misspelled, panicked fragments. Interpret them charitably. Do not ask clarifying questions unless dangerously ambiguous.
9. If the message suggests the person is unconscious, not breathing, or bleeding heavily, address that first.
10. Do not provide guidance for deliberately harming any person.
11. Never begin with "I'm sorry", "I can't", or "I'm not a medical professional".
12. Two absolute rules: (a) In a severe allergic reaction (face or throat swelling, wheezing after a sting) with an epinephrine auto-injector available, helping the person use it IMMEDIATELY is always correct - never advise waiting for permission. (b) A tourniquet that has been applied must NEVER be loosened or removed outside a medical facility."""

# Small talk answered deterministically - no RAG, no LLM, no MT. A 3B model
# with a context full of emergency passages cannot be trusted to classify
# "how are u" reliably (observed: it fell back to "my references don't cover
# this"). Full-string match only, so real questions are never hijacked.
_ST_SQ = (r"pershendetje|përshëndetje|tungjatjeta|tung|ckemi|ç'?kemi"
          r"|mir[ëe]mbr[ëe]ma|mir[ëe]m[ëe]ngjes\w*|mir[ëe]dita"
          r"|si je(ni)?|si kalon(i)?|a je mir[ëe]|faleminderit|flm|rrofsh"
          r"|kush je( ti)?|[çc]far[ëe] je ti|[çc]far[ëe] di t[ëe] b[ëe]sh|si punon")
_ST_EN = (r"hello|hi|hey|good (morning|evening|afternoon)|how are (you|u)|how r u"
          r"|what'?s up|thank you|thanks|thx|who are (you|u)|what are (you|u)"
          r"|what can (you|u) do|how do (you|u) work")
_ST_FULL = re.compile(r"^(\s*(%s|%s)[\s,!.?]*)+$" % (_ST_SQ, _ST_EN), re.IGNORECASE)


def _smalltalk(q):
    t = (q or "").strip().lower()
    if not t or len(t) > 60 or not _ST_FULL.match(t):
        return None
    sq = bool(re.search(_ST_SQ, t, re.IGNORECASE))
    if re.search(r"kush je|[çc]far[ëe] (je|di)|si punon|who are|what (are|can)|how do", t, re.IGNORECASE):
        return ("Jam NOAH - udhëzues i ndihmës së parë pa internet, në shqip dhe anglisht. "
                "Shkruaj pyetjen e urgjencës dhe shtyp ENTER." if sq else
                "I am NOAH - an offline first-aid guide in Albanian and English. "
                "Type your emergency question and press ENTER.")
    if re.search(r"faleminderit|flm|rrofsh|thank|thx", t, re.IGNORECASE):
        return ("S'ka gjë. Jam këtu nëse të duhet ndihmë." if sq else
                "You're welcome. I'm here if you need help.")
    return ("Mirë. Jam NOAH, udhëzuesi i ndihmës së parë. Shkruaj pyetjen dhe shtyp ENTER."
            if sq else
            "Fine. I am NOAH, the first-aid guide. Type your question and press ENTER.")
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

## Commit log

2026-09-03 NOAH offline first-aid terminal: software, hardware docs, 3D models
    Complete DIY build: Jetson Orin Nano + 7.8" e-ink IT8951 + BB Q10 keyboard.
    Bilingual (Albanian/English) offline RAG over first-aid references with a
    50-rule deterministic safety layer, e-ink field UI, printable enclosure.
    [NOAH_BasePlate.stl, NOAH_Bumper_Back.stl, NOAH_Bumper_Bottom.stl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]
2026-09-03 Replace em/en dashes with hyphens across all text
    [assistant.py, eink.py, noah_ui.py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]
2026-09-03 Remove prototype photo from repo
2026-09-04 Fix nosebleed MT howler: 'flisni gjak' -> 'pështyni gjakun'
    [translator.py]
2026-09-10 Answer pages: 1cm (118px) text padding on all sides
2026-09-10 Home screen: 1cm input-box padding + subtitle to Offline AI assistant
2026-09-10 Home screen: move corner labels (status, american.al) to 1cm margins
2026-09-10 Route non-first-aid questions to a general-knowledge answer
    Fixes off-topic questions (e.g. 'world war 2') getting combat first-aid
    pulled from the survival manual. A no-passage classifier decides FIRSTAID
    vs GENERAL; a fired safety rule always forces FIRSTAID. General questions
    answer from plain knowledge with no first-aid passages.
    [assistant.py]
2026-09-11 Boot: early e-ink splash service + panel-init robustness
    Add noah-splash.service: a tiny, early, oneshot unit that imports only the
    panel driver (never the assistant pipeline) to paint the loading screen as
    soon as the SPI/GPIO come up, then releases the panel so noah_ui takes over.
    The e-ink holds the image through the heavy UI startup. Ordered on the rootfs
    (not local-fs.target, which waits on docker's mounts) with an early-start
    drop-in for fix-gpio-pinmux.
    eink.py: release partially-acquired SPI/GPIO if __init__ fails, so an
    early-boot transient (SPI1 pads still settling) no longer poisons every retry
    with EBUSY on our own held lines.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
    [eink.py, noah_splash.py]
2026-09-11 eink: retry device-info read on cold-boot SPI desync
    The GET_DEV_INFO read occasionally comes back shifted at cold boot (observed
    height=1872 instead of 1404). That single bad read used to raise 'bad device
    info', disable the panel, and FATAL the UI - forcing a full crash-restart
    (~20s at boot: a 5s restart plus a second cold import). Fold the read into the
    reset retry loop so a desynced read just resets and re-reads. Boot now has
    zero noah-ui restarts and typing-ready dropped ~10s.
    [eink.py]
2026-09-11 Revert the 5s loading-screen hold (back out fb55fed)
    Reverted at user request. Note: the panel fault seen afterward (IT8951 HRDY
    timeout / BUSY line stuck low) is unrelated to this change - it is the e-ink
    controller not responding, a power/connection issue that needs a physical
    power cycle.
    [noah_ui.py]
